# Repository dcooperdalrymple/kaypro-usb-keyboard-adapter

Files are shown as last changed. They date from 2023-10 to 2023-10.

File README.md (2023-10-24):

# Kaypro USB Keyboard Adapter
Adapter for the Kaypro 2 to replace the original keyboard with a USB keyboard. Uses the Raspberry Pi Pico as a USB host and for serial communication to the RJ11 port on the Kaypro.

## Compiling Firmware

* Configuring: `cmake -B build -S .`
* Compiling/Building: `make -C build`
* Writing: Hold BOOTSEL button on Pico, plug it in via USB, and release BOOTSEL. Copy and paste `kaypro-usb.uf2` into RPI-RP2 drive.

## Hardware

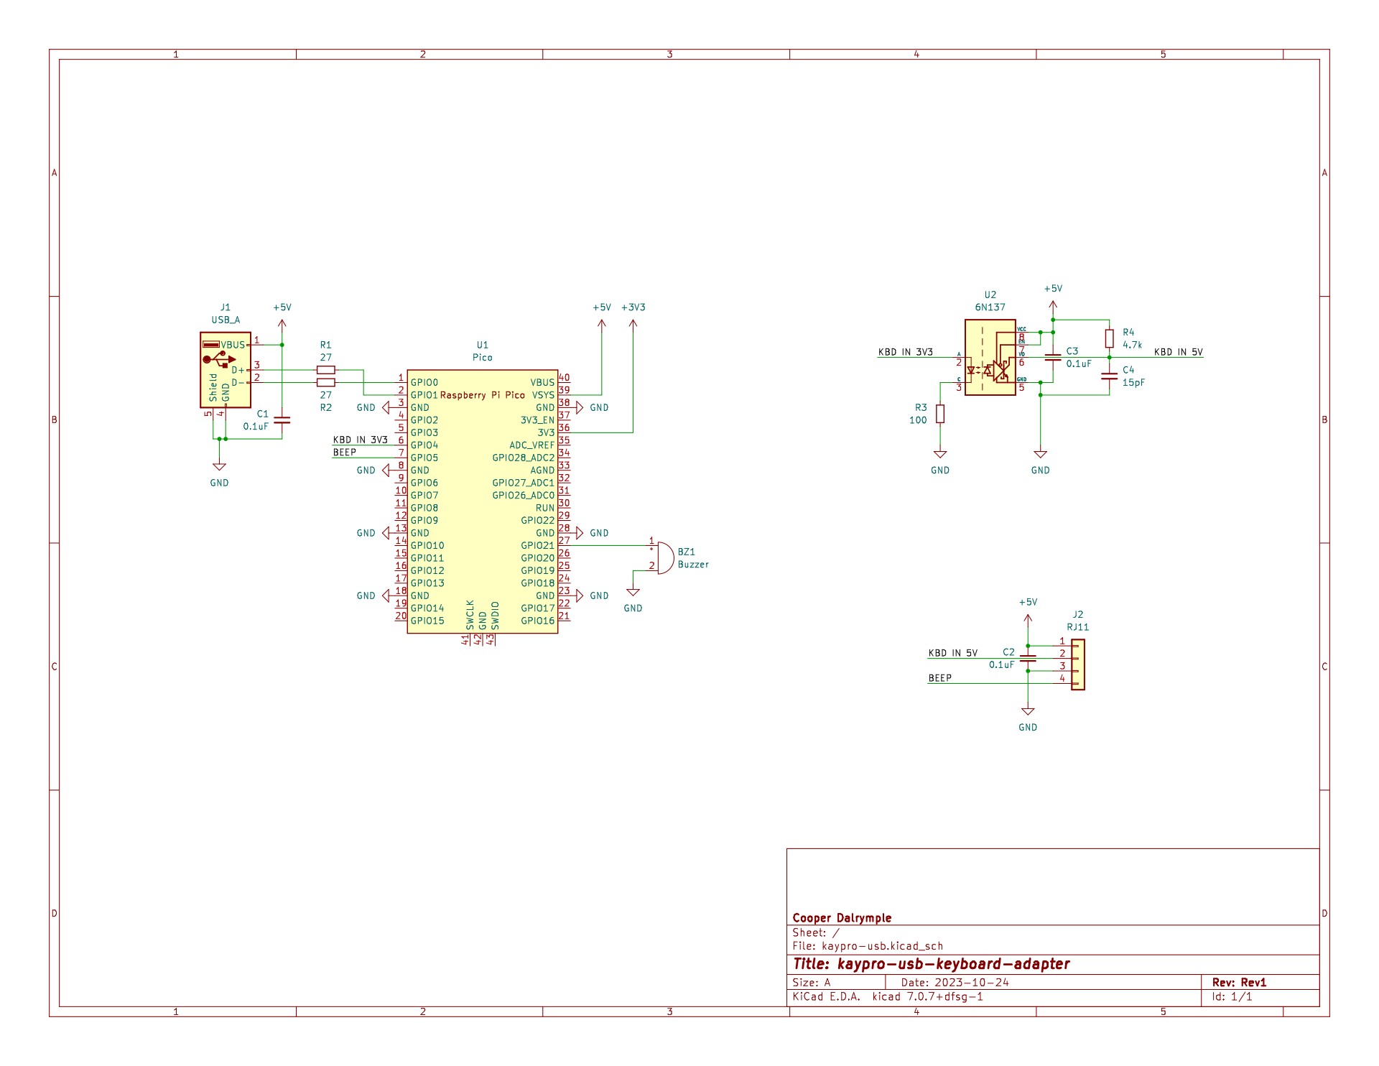
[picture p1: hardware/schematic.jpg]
schematic Kaypro USB Keyboard Adapter Schematic


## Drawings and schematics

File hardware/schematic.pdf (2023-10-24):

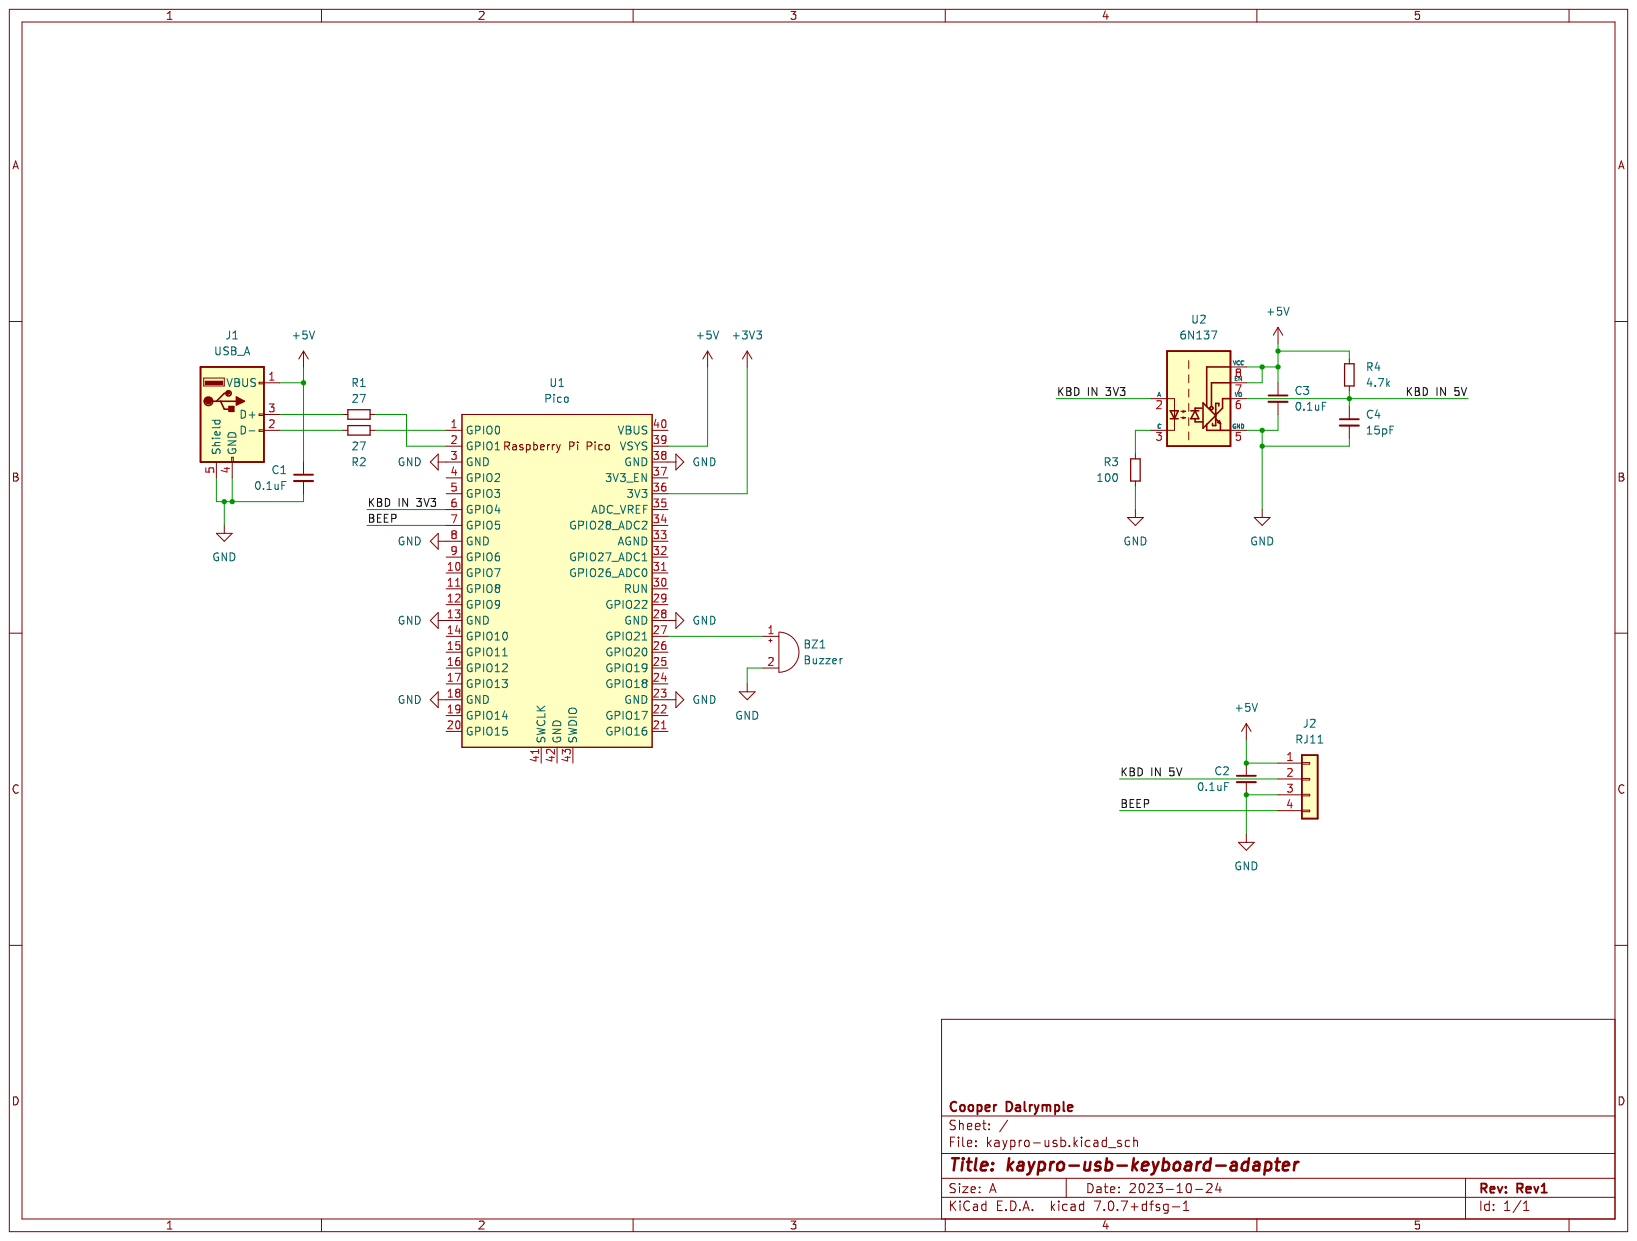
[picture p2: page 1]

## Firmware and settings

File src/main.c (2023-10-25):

/**
 * kaypro-usb-keyboard-adapter: main.cpp
 * @author Cooper Dalrymple
 * @version 1.0
 * @since 1.0
 */

#include <stdio.h>
#include <stdlib.h>
#include <string.h>

#include "pico/stdlib.h"
#include "pico/binary_info.h"
#include "pico/multicore.h"
#include "pico/bootrom.h"
#include "hardware/gpio.h"

#include "pio_usb.h"

#include "config.h"
#include "keyboard.h"
#include "led.h"
#include "buzzer.h"
#include "kaypro.h"
#include "uart.h"

//#define DEBUG
//#define DEBUG_PUTCHAR

#define EP_NUM_KEYBOARD 0x81

const char* const program_description = "Kaypro USB Keyboard Adapter v1.0";

static usb_device_t *usb_device = NULL;

void usb_main(void);
void core1_main(void);

int main() {
    // Default system clock of 125MHz is not appropriate, should be multiple of 12MHz.
    set_sys_clock_khz(SYSCLK_KHZ, true);

    // picotool declarations
    bi_decl(bi_program_description(program_description));

    stdio_init_all();
    printf(program_description);
    printf("\r\n");

    sleep_ms(10);

    multicore_reset_core1();
    // All USB task run in core1
    multicore_launch_core1(core1_main);

    led_init();
    buzzer_init();
    uart_start();

    while (1) {
        usb_main();
        buzzer_update();

        stdio_flush();
        sleep_us(10);
    }

    return 0;
}

void usb_main(void) {
    if (usb_device == NULL) return;

    bool has_connected = false;

    for (int dev_idx = 0; dev_idx < PIO_USB_DEVICE_CNT; dev_idx++) {
        usb_device_t *device = &usb_device[dev_idx];
        if (!device->connected) continue;

        has_connected = true;

        // Print received packet to EPs
        for (int ep_idx = 0; ep_idx < PIO_USB_DEV_EP_CNT; ep_idx++) {
            endpoint_t *ep = pio_usb_get_endpoint(device, ep_idx);
            if (ep == NULL) break;
            if (ep->ep_num != EP_NUM_KEYBOARD) continue;

            uint8_t temp[64];
            int len = pio_usb_get_in_data(ep, temp, sizeof(temp));
            if (len != 8) continue;

            keyboard_update(temp);
            #ifdef DEBUG
            keyboard_print();
            #endif
        }
    }

    led_set_connected(has_connected);
}

void keyboard_press(uint8_t keycode, KeyboardState * state) {
    led_set_capslock(state->capslock);

    #if defined(DEBUG) || defined(DEBUG_PUTCHAR)
    uint8_t ch = keyboard_get_ascii(keycode, state);
    #endif
    uint8_t data = kaypro_get_data(keycode, state);

    #ifdef DEBUG
    printf(":: PRESS ::\r\n");
    printf("HID = %02x\r\n", keycode);
    printf("ASCII = %02x\r\n", ch);
    printf("KAYPRO = %02x\r\n", data);
    #endif

    #ifdef DEBUG_PUTCHAR
    if (ch) putchar(ch);
    #endif

    if (data != KP_KEY_NONE) {
        uart_write(data);
        buzzer_trigger();
    }
}
void keyboard_release(uint8_t keycode, KeyboardState * state) {
    #ifdef DEBUG
    uint8_t ch = keyboard_get_ascii(keycode, state);
    uint8_t data = kaypro_get_data(keycode, state);

    printf(":: RELEASE ::\r\n");
    printf("HID = %02x\r\n", keycode);
    printf("ASCII = %02x\r\n", ch);
    printf("KAYPRO = %02x\r\n", data);
    #endif
}

void core1_main(void) {
    sleep_ms(10);

    // To run USB SOF interrupt in core1, create alarm pool in core1.
    static pio_usb_configuration_t config = PIO_USB_DEFAULT_CONFIG;
    config.alarm_pool = (void*)alarm_pool_create(2, 1);
    usb_device = pio_usb_host_init(&config);

    while (1) {
        pio_usb_host_task();
    }
}

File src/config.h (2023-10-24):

/**
 * kaypro-usb-keyboard-adapter: config.h
 * @author Cooper Dalrymple
 * @version 1.0
 * @since 1.0
 */

#ifndef CONFIG_H_
#define CONFIG_H_

#include <stdio.h>
#include <stdlib.h>
#include "pico/stdlib.h"

#define SYSCLK_MHZ          120
#define SYSCLK_KHZ          SYSCLK_MHZ*1000

// UART Serial
#define UART_ID             uart1
#define UART_BAUD_RATE      300
#define UART_TX_PIN         4
#define UART_RX_PIN         5
#define UART_BUFFER_SIZE    32
#define UART_DATA_BITS      8
#define UART_STOP_BITS      1
#define UART_PARITY         0

#define LED_PIN             25

#define BUZZER_PIN          21
#define BUZZER_FREQ         60
#define BUZZER_MS           20
#define BUZZER_DUTY         0.5

#define millis()            (to_ms_since_boot(get_absolute_time()))

#endif

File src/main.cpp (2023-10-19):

/**
 * kaypro-usb-keyboard-adapter: main.cpp
 * @author Cooper Dalrymple
 * @version 1.0
 * @since 1.0
 */

#include <stdio.h>
#include <stdlib.h>
#include <string.h>

#include "pico/stdlib.h"
#include "pico/binary_info.h"
#include "pico/multicore.h"
#include "pico/bootrom.h"
#include "hardware/gpio.h"

#include "pio_usb.h"

#include "config.h"

const char* const program_description = "Kaypro USB Keyboard Adapter v1.0";

static usb_device_t *usb_device = NULL;

void core1_main(void);

void usb_main(void);
void read_keyboard_state(uint8_t * data);
void print_keyboard_state(void);
void led_main(void);

int main() {
    // default 125MHz is not appropreate. Sysclock should be multiple of 12MHz.
    set_sys_clock_khz(120000, true);

    // picotool declarations
    bi_decl(bi_program_description(program_description));

    stdio_init_all();
    printf(program_description);
    printf("\r\n");

    sleep_ms(10);

    multicore_reset_core1();
    // All USB task run in core1
    multicore_launch_core1(core1_main);

    gpio_init(LED_PIN);
    gpio_set_dir(LED_PIN, GPIO_OUT);

    while (1) {
        usb_main();
        led_main();

        stdio_flush();
        sleep_us(10);
    }

    return 0;
}

void usb_main(void) {
    if (usb_device == NULL) return;

    for (int dev_idx = 0; dev_idx < PIO_USB_DEVICE_CNT; dev_idx++) {
        usb_device_t *device = &usb_device[dev_idx];
        if (!device->connected) continue;

        // Print received packet to EPs
        for (int ep_idx = 0; ep_idx < PIO_USB_DEV_EP_CNT; ep_idx++) {
            endpoint_t *ep = pio_usb_get_endpoint(device, ep_idx);

            if (ep == NULL) break;

            uint8_t temp[64];
            int len = pio_usb_get_in_data(ep, temp, sizeof(temp));

            // Logitech Unified Receiver
            if (device->vid == 0x046d && device->pid == 0xc52b && ep->ep_num == 0x81 && len == 8) {
                read_keyboard_state(temp);
                print_keyboard_state();
            }
        }
    }
}

struct {
    bool ctrl;
    bool shift;
    bool caps;
    uint8_t keys[6];
    uint8_t num_keys;
} keyboardState;

// https://kevinboone.me/pico_usb_kbd_lcd.html?i=1
// https://www.win.tue.nl/~aeb/linux/kbd/scancodes-14.html
void read_keyboard_state(uint8_t * data) {
    uint8_t i;

    keyboardState.ctrl = data[0] & 0x01;
    keyboardState.shift = data[0] & 0x02;

    keyboardState.num_keys = 6;
    for (i = 0; i < 6; i++) {
        if (data[i+2] != 0x00) continue;
        keyboardState.num_keys = i;
        break;
    }
    for (i = 0; i < 6; i++) {
        keyboardState.keys[i] = data[i+2];
    }
}

void print_keyboard_state() {
    printf("CTRL = ");
    if (keyboardState.ctrl) {
        printf("ON\r\n");
    } else {
        printf("OFF\r\n");
    }

    printf("SHIFT = ");
    if (keyboardState.shift) {
        printf("ON\r\n");
    } else {
        printf("OFF\r\n");
    }

    printf("KEYS = %d\r\n", keyboardState.num_keys);
    for (uint8_t i = 0; i < keyboardState.num_keys; i++) {
        printf("%02x ", keyboardState.keys[i]);
    }
    printf("\r\n\r\n");
}

void led_main(void) {
    const uint32_t interval_ms = 1000;
    static uint32_t start_ms = to_ms_since_boot(get_absolute_time());

    static bool led_state = false;

    if (to_ms_since_boot(get_absolute_time()) - start_ms < interval_ms) return;
    start_ms += interval_ms;

    led_state = !led_state;
    gpio_put(LED_PIN, led_state);
}

void core1_main(void) {

    sleep_ms(10);

    // To run USB SOF interrupt in core1, create alarm pool in core1.
    static pio_usb_configuration_t config = PIO_USB_DEFAULT_CONFIG;
    config.alarm_pool = (void*)alarm_pool_create(2, 1);
    usb_device = pio_usb_host_init(&config);

    while (1) {
        pio_usb_host_task();
    }
}

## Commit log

2023-10-18 Basic implementation of pico-examples host_cdc_msc_hid.
2023-10-19 Converted to use Pico-PIO-USB library. Includes basic debug serial output with specific keyboard.
2023-10-19 Simple pwm buzzer CircuitPython test.
    [buzzer.py]
2023-10-19 Basic hardware schematic.
    [kaypro-usb.kicad_pcb, kaypro-usb.kicad_sch]
2023-10-19 Removed temporary PCB file.
    [kaypro-usb.kicad_pcb]
2023-10-23 Track capslock state.
2023-10-23 Led indication of usb device connection and caps lock.
2023-10-23 Debug flags added with ascii char printing.
2023-10-24 Define UART data format.
2023-10-24 UART transmit functionality complete.
2023-10-24 Added 6n137 optoisolator for level shifting. UART Tx inverted to complement 6n137 inversion.
    [kaypro-usb.kicad_sch]
2023-10-24 Added schematic to readme.
    [kaypro-usb.kicad_sch]
2023-10-24 Added diode to prevent USB power leaking to the Kaypro when debugging.
    [kaypro-usb.kicad_sch]
2023-10-25 Use lookup table for kaypro keycode. Keycodes still require testing.
    [hid-conversion-table.ods]
2023-10-25 Only trigger buzzer when valid key is entered.
    [main.c]
